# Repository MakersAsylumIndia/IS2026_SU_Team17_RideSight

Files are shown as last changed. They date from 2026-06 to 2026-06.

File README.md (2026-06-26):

# IS2026 Spring - RideSight

Problem Statement-
Motorcycle/Scooter drivers, especially those working for delivery companies, rely heavily on smartphone navigation to complete their journeys. However, checking directions requires them to repeatedly look down at their phones, diverting their attention away from the road. As the number of delivery drivers continues to grow, there is an increased likelihood of them getting into a severe accident, creating an urgent need for a safer, hands-free navigation solution that allows riders to receive directions in real-time.

Solution-
We are developing a smart navigation attachment for a motorcycle helmet with an embedded ESP32 and two RGB LEDs: one on the left and one on the right. The ESP32 will be connected wirelessly over bluetooth to a navigation application on the user's phone. The navigation application will provide real-time instructions, which will be transmitted to the ESP32. The ESP32 will then control the LED lights placed on both sides of the helmet. For example, if the user has to go right, the LED light on the right side of the helmet will blink.

Future Prospects-
This project could be further developed by integrating additional navigation cues and expanding compatibility with different navigation applications. In the future, the system could be adopted by delivery companies to improve rider safety and reduce accidents caused by distracted driving.

Contents of all the folders-
1. **CAD** contains all of the files of the components which we 3D printed/laser cut for our project.
2. **Code** contains the codes for our project.
3. **Documentation** contains the steps to making this project.
4. **Electronics** contains the circuit diagram with all the components which we used for our project.
5. **Photos_Videos** contains photos and videos of the working prototype.
6. **Reference_Data** contains all the references that we used.
7. **BOM.csv** contains all the electrical components that we used.

## License

Licenses

<a href="LICENSE.md">Open Source Licenses Facts</a>

#### Hardware
CERN Open Hardware License Version 2 - Strongly Reciprocal ([CERN-OHL-S-2.0](https://spdx.org/licenses/CERN-OHL-S-2.0.html)).

#### Software
MIT open source [license](http://opensource.org/licenses/MIT).

#### Documentation:
<br />This work is licensed under a <a rel="license" href="http://creativecommons.org/licenses/by/4.0/">Creative Commons Attribution 4.0 International License</a>.

---

## 📬 Contact/Team

> _List team members and contact emails or GitHub profiles._
[@anool](https://github.com/Anool)
> 
>
> ---

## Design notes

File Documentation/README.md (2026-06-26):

We first used Mapbox API and designed a webapp for our navigation system. Then we linked our ESP 32 to this webapp using bluetooth. After finalising the circuit and the components, we designed and 3D printed a box to fit all of the components. This box is supposed to be attached to the helmet using a sliding mechanism which we designed and 3D printed. Finally we mounted the LEDs on the helmet and connected them to the box. The box is detachable so that the user the charge the Li-Po battery inside which powers the entire circuit. The user just has to put the location of where they want to go to on the webapp and the LEDs will indicate direction accordingly.

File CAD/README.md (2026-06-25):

There are files for 3 different components-
the box which we used to store all our electrical components,
the lid for the box which we laser cut,
and the sliding mechanism which we used to easily put on and remove the box from the helmet.

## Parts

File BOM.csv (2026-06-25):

Name of the Material/Component | Quantity | Reference Link | Additional Note
ESP 32 | 1 | https://robocraze.com/products/esp32-development-board?variant=40193649803417&country=IN&currency=INR | Main microcontroller on which the project is based
RGB LEDs | 2 | https://robu.in/product/ws2812b-rgb-addressable-led-module/ | RGB LEDs provide visual cues to the rider and blink in certain patterns telling the driver when to make turns
Battery Charging Module | 1 | https://robu.in/product/tp4056-1a-li-ion-lithium-battery-charging-module-with-current-protection-type-c/ | To charge the battery
LiPo Battery | 1 | https://robu.in/product/wly602540-600mah-3-7v-single-cell-rechargeable-lipo-battery/ | Battery to power the circuit
DC Booster | 1 | https://robu.in/product/xl6009-dc-dc-step-up-converter-performance-ultra-lm2577-booster-circuit-board/ | To boost the 3.7V voltage of the battery to 5V to power the ESP 32
Slide switch | 1 | https://robu.in/product/slide-switch-sk-09/ | To turn the circuit on/off

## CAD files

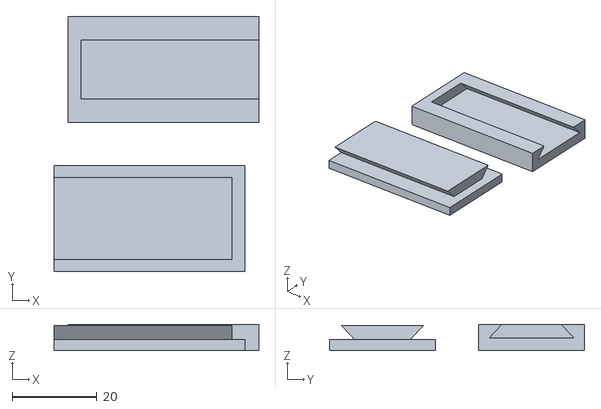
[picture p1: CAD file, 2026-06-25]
CAD/Team 17 MA RideSight Sliding Mechanism STL.stl
48.3 x 60.2 x 6.21

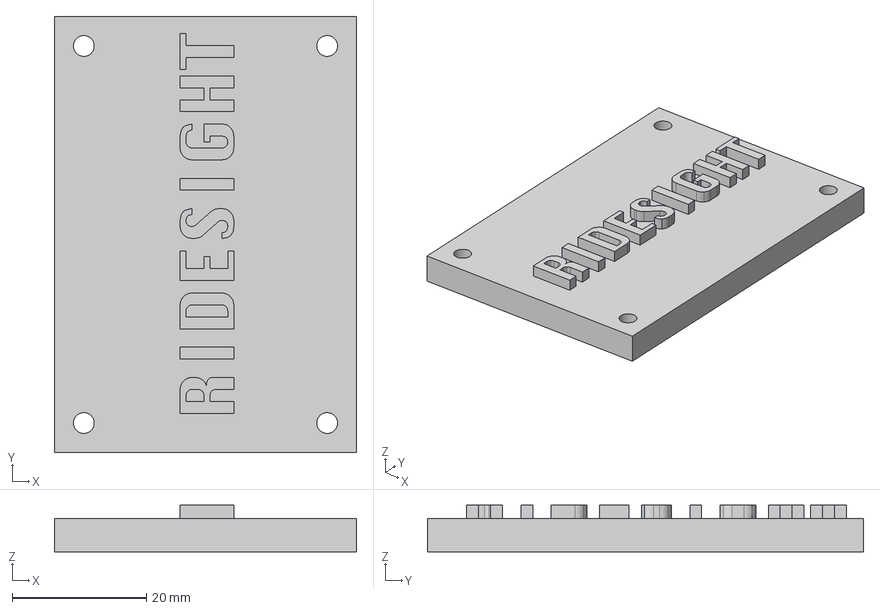
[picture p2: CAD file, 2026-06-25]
CAD/Team 17- Box lid.step
45.0 x 65.0 x 7.00 mm

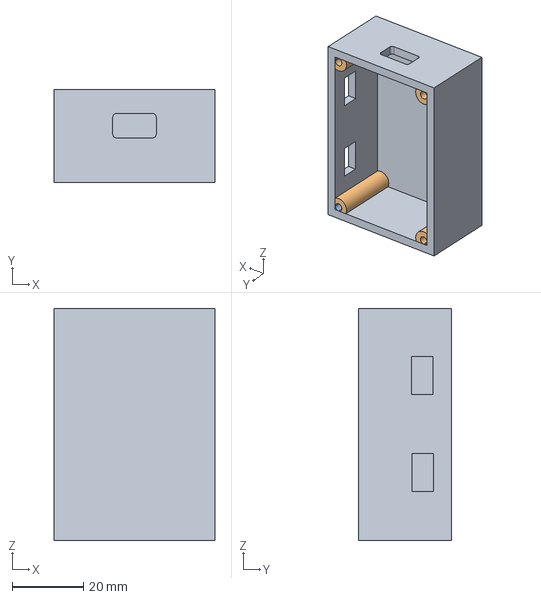
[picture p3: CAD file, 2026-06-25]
CAD/Team17_RideSight_box.step
45.0 x 26.0 x 65.0 mm

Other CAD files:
CAD/Team 17 MA RideSight Sliding Mechanism STEP Format.step
CAD/Team 17 MA RideSight Sliding Mechanism F3D Format.f3d
CAD/Team 17- Box lid.f3d
CAD/Team 17- Box lid.stl
CAD/Team17_RideSight_box.f3d
CAD/Team17_RideSight_box.stl

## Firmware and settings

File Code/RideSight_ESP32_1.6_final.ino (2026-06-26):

/*
 * RideSight — ESP32 (Arduino IDE)  ·  FINAL (Adafruit NeoPixel)
 * Two WS2812B LEDs on separate pins:  right = GPIO5 (D5)   left = GPIO25 (D25)
 * Each pin is its own NeoPixel object (NeoPixel uses one strip per data pin).
 *
 * Functions (5): LEFT_TURN, RIGHT_TURN, LEFT_UTURN, RIGHT_UTURN, ARRIVE  (STRAIGHT = off)
 *
 * Turn  -> respective side LED, SOLID colour by distance:
 *        x > 400        : off
 *        400 >= x > 200 : green
 *        200 >= x > 100 : yellow
 *        100 >= x > 0   : red
 * U-turn -> respective side LED SOLID BLUE when distance < 200 m
 * Arrive -> BOTH LEDs BLINK MAGENTA when distance < 50 m
 *
 * Wire format (3 bytes, must match protocol.js):
 *   byte0 = turn (0=STRAIGHT 1=LEFT_TURN 2=RIGHT_TURN 3=LEFT_UTURN 4=RIGHT_UTURN 5=ARRIVE)
 *   byte1 = distance high byte (uint16 big-endian, metres)   byte2 = distance low byte
 *
 * Libraries (Arduino IDE -> Library Manager):
 *   - "Adafruit NeoPixel"
 *   - "NimBLE-Arduino" (h2zero, 2.x)
 * Board: match your ESP32 variant.  NOTE: GPIO25 doesn't exist on ESP32-C3.
 * Diagnostics (default off): LED_TEST cycles LEDs ignoring BLE; SIMULATE sweeps real patterns.
 */

#include <NimBLEDevice.h>
#include <Adafruit_NeoPixel.h>

// ───────── config ─────────
#define SERVICE_UUID   "6686e2e2-25d8-4172-818f-0886d4e8f695"   // paste EXACT from config.js
#define CHAR_CMD_UUID  "0b64cb22-701b-415d-b32c-26a5483ea35d"
#define DEVICE_NAME    "RideSight"

#define PIN_RIGHT   5      // D5
#define PIN_LEFT    25     // D25

#define BRIGHTNESS            150     // bench-tune against visor glare
#define UTURN_DIST_M          200     // U-turn LED shows under this
#define ARRIVE_DIST_M         50      // magenta flash under this
#define HEARTBEAT_TIMEOUT_MS  3000    // no packet this long -> all off (fail-safe)

#define LED_TEST 0     // 1 = ignore BLE, cycle LEDs to verify wiring/power
#define SIMULATE 0     // 1 = sweep the real patterns with no phone

// packed 0xRRGGBB colours (NeoPixel reorders per NEO_GRB)
#define COL_OFF     0x000000
#define COL_RED     0xFF0000
#define COL_GREEN   0x00FF00
#define COL_BLUE    0x0000FF
#define COL_YELLOW  0xFFFF00
#define COL_MAGENTA 0xFF00FF
#define COL_WHITE   0xFFFFFF

enum Turn : uint8_t { STRAIGHT = 0, LEFT_TURN, RIGHT_TURN, LEFT_UTURN, RIGHT_UTURN, ARRIVE };

// ───────── LEDs (one NeoPixel object per pin) ─────────
Adafruit_NeoPixel right(1, PIN_RIGHT, NEO_GRB + NEO_KHZ800);
Adafruit_NeoPixel left (1, PIN_LEFT,  NEO_GRB + NEO_KHZ800);

// ───────── state ─────────
volatile uint8_t  g_turn   = STRAIGHT;
volatile uint16_t g_dist   = 0;
volatile uint32_t g_lastRx = 0;

static void setLeds(uint32_t l, uint32_t r) {
  left.setPixelColor(0, l);   left.show();
  right.setPixelColor(0, r);  right.show();
}

// ───────── BLE ─────────
class CmdCallbacks : public NimBLECharacteristicCallbacks {
  void onWrite(NimBLECharacteristic* c, NimBLEConnInfo& info) override {
    NimBLEAttValue v = c->getValue();
    if (v.size() >= 3) {
      const uint8_t* p = v.data();
      g_turn   = p[0];
      g_dist   = ((uint16_t)p[1] << 8) | p[2];   // big-endian
      g_lastRx = millis();
      Serial.printf("rx turn=%u dist=%u\n", g_turn, g_dist);
    }
  }
};

static void startBLE() {
  NimBLEDevice::init(DEVICE_NAME);
  NimBLEServer* server = NimBLEDevice::createServer();
  server->advertiseOnDisconnect(true);
  NimBLEService* svc = server->createService(SERVICE_UUID);
  NimBLECharacteristic* cmd = svc->createCharacteristic(
      CHAR_CMD_UUID, NIMBLE_PROPERTY::WRITE | NIMBLE_PROPERTY::WRITE_NR);
  cmd->setCallbacks(new CmdCallbacks());
  svc->start();

  NimBLEAdvertisementData advData;
  advData.setFlags(BLE_HS_ADV_F_DISC_GEN | BLE_HS_ADV_F_BREDR_UNSUP);
  advData.addServiceUUID(SERVICE_UUID);
  NimBLEAdvertisementData scanData;
  scanData.setName(DEVICE_NAME);
  NimBLEAdvertising* adv = NimBLEDevice::getAdvertising();
  adv->setAdvertisementData(advData);
  adv->setScanResponseData(scanData);
  adv->enableScanResponse(true);
  NimBLEDevice::startAdvertising();
}

// distance -> solid zone colour (off above 400 m)
static uint32_t zoneColor(uint16_t x) {
  if (x > 400) return COL_OFF;
  if (x > 200) return COL_GREEN;    // 400..201
  if (x > 100) return COL_YELLOW;   // 200..101
  return COL_RED;                   // 100..0
}

static void bootSelfTest() {
  uint32_t seq[] = { COL_RED, COL_GREEN, COL_BLUE };
  for (uint32_t col : seq) { setLeds(col, col); delay(300); }
  setLeds(COL_OFF, COL_OFF);
}

void setup() {
  Serial.begin(115200);
  delay(200);
  Serial.printf("RideSight FINAL (NeoPixel)  RIGHT=GPIO%d LEFT=GPIO%d  LED_TEST=%d SIMULATE=%d\n",
                PIN_RIGHT, PIN_LEFT, LED_TEST, SIMULATE);

  right.begin(); right.setBrightness(BRIGHTNESS); right.show();
  left.begin();  left.setBrightness(BRIGHTNESS);  left.show();
  bootSelfTest();   // if nothing shows here, it's wiring/power/pin — not BLE/website

#if !LED_TEST && !SIMULATE
  startBLE();
  Serial.println("RideSight advertising…");
#endif
}

void loop() {
  uint32_t now = millis();

#if LED_TEST
  uint32_t test[] = { COL_RED, COL_GREEN, COL_BLUE, COL_WHITE };
  uint32_t c = test[(now / 700) % 4];
  setLeds(c, c); delay(10); return;
#endif

#if SIMULATE
  struct Case { uint8_t turn; uint16_t dist; };
  static const Case cases[] = {
    {LEFT_TURN,350},{LEFT_TURN,150},{LEFT_TURN,60},
    {RIGHT_TURN,150},{LEFT_UTURN,150},{RIGHT_UTURN,150},{ARRIVE,40},
  };
  const Case& c = cases[(now / 3000) % (sizeof(cases)/sizeof(cases[0]))];
  g_turn = c.turn; g_dist = c.dist; g_lastRx = now;
#endif

  uint8_t  turn = g_turn;
  uint16_t dist = g_dist;
  uint32_t lColor = COL_OFF, rColor = COL_OFF;

  bool haveData = (g_lastRx != 0);
  bool stale    = haveData && (now - g_lastRx > HEARTBEAT_TIMEOUT_MS);

  if (haveData && !stale) {
    switch (turn) {
      case LEFT_TURN:   lColor = zoneColor(dist); break;   // solid, no blink
      case RIGHT_TURN:  rColor = zoneColor(dist); break;
      case LEFT_UTURN:  if (dist < UTURN_DIST_M) lColor = COL_BLUE; break;
      case RIGHT_UTURN: if (dist < UTURN_DIST_M) rColor = COL_BLUE; break;
      case ARRIVE:
        if (dist < ARRIVE_DIST_M && ((now / 250) % 2))       // ~2 Hz flash
          lColor = rColor = COL_MAGENTA;
        break;
      case STRAIGHT:
      default: break;
    }
  }

  setLeds(lColor, rColor);
  delay(10);
}

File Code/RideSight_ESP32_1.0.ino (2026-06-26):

/*
 * RideSight — ESP32 (Arduino IDE)
 * Three WS2812B LEDs on SEPARATE data pins:
 *   left = GPIO5 (D5), centre = GPIO18 (D18), right = GPIO19 (D19)
 *
 * LED behaviour (this version):
 *   RIGHT_TURN  -> fade the RIGHT LED  (breathing fade)
 *   LEFT_TURN   -> fade the LEFT  LED  (breathing fade)
 *   LEFT_UTURN  -> LEFT  LED solid BLUE when distance < 500 m (else off)
 *   RIGHT_UTURN -> RIGHT LED solid BLUE when distance < 500 m (else off)
 *   STRAIGHT    -> nothing (centre LED has no assigned pattern yet)
 *
 * turn + distance arrive over BLE from the phone (3-byte payload, must match
 * the web app's protocol.js):
 *   byte 0 = turn (0=STRAIGHT 1=LEFT_TURN 2=RIGHT_TURN 3=LEFT_UTURN 4=RIGHT_UTURN)
 *   byte 1 = distance high byte (uint16, big-endian, metres)
 *   byte 2 = distance low  byte
 *
 * Libraries (Arduino IDE -> Library Manager):
 *   - "NimBLE-Arduino" by h2zero   (this code needs 2.x)
 *   - "FastLED"
 * Board: "ESP32 Dev Module" (Espressif esp32 core).
 */

#include <NimBLEDevice.h>
#include <FastLED.h>

// ───────── config ─────────
// Paste the EXACT UUIDs from your web app's src/config.js (prefixes are hints).
#define SERVICE_UUID   "6686e2e2-25d8-4172-818f-0886d4e8f695"
#define CHAR_CMD_UUID  "0b64cb22-701b-415d-b32c-26a5483ea35d"
#define DEVICE_NAME    "RideSight"

#define PIN_LEFT    5     // D5
#define PIN_CENTRE  18    // D18
#define PIN_RIGHT   19    // D19

#define BRIGHTNESS        100  // global ceiling — BENCH-TUNE against visor glare
#define FADE_BPM          30    // breathing fade speed (breaths/min) — tunable
#define TURN_HUE          32    // fade colour for turns (FastLED HSV: ~32 = amber). Blue is reserved for U-turns.
#define UTURN_DIST_M      500   // U-turn LED shows only under this distance
#define HEARTBEAT_TIMEOUT_MS 3000  // no packet this long -> LEDs off (fail-safe)

#define SIMULATE 0       // set to 1 to cycle the patterns WITHOUT a phone (bench test)

enum Turn : uint8_t { STRAIGHT = 0, LEFT_TURN, RIGHT_TURN, LEFT_UTURN, RIGHT_UTURN };

// ───────── state ─────────
CRGB ledLeft[1], ledCentre[1], ledRight[1];
volatile uint8_t  g_turn   = STRAIGHT;
volatile uint16_t g_dist   = 0;
volatile uint32_t g_lastRx = 0;

// ───────── BLE ─────────
class CmdCallbacks : public NimBLECharacteristicCallbacks {
  void onWrite(NimBLECharacteristic* c, NimBLEConnInfo& info) override {
    NimBLEAttValue v = c->getValue();
    if (v.size() >= 3) {
      const uint8_t* p = v.data();
      g_turn   = p[0];
      g_dist   = ((uint16_t)p[1] << 8) | p[2];   // big-endian
      g_lastRx = millis();
    }
  }
};

static void startBLE() {
  NimBLEDevice::init(DEVICE_NAME);
  NimBLEServer* server = NimBLEDevice::createServer();
  server->advertiseOnDisconnect(true);           // 2.x: auto re-advertise is OFF by default

  NimBLEService* svc = server->createService(SERVICE_UUID);
  NimBLECharacteristic* cmd = svc->createCharacteristic(
      CHAR_CMD_UUID, NIMBLE_PROPERTY::WRITE | NIMBLE_PROPERTY::WRITE_NR);
  cmd->setCallbacks(new CmdCallbacks());
  svc->start();

  // Service UUID in the MAIN advertisement packet (Web Bluetooth / Bluefy filter
  // on it); device NAME in the scan response (both won't fit in 31 bytes).
  NimBLEAdvertisementData advData;
  advData.setFlags(BLE_HS_ADV_F_DISC_GEN | BLE_HS_ADV_F_BREDR_UNSUP);
  advData.addServiceUUID(SERVICE_UUID);
  NimBLEAdvertisementData scanData;
  scanData.setName(DEVICE_NAME);

  NimBLEAdvertising* adv = NimBLEDevice::getAdvertising();
  adv->setAdvertisementData(advData);
  adv->setScanResponseData(scanData);
  adv->enableScanResponse(true);                 // 2.x: must enable explicitly
  NimBLEDevice::startAdvertising();
}

// ───────── boot self-test: R, G, B on each LED so you can verify wiring/colour ─────────
static void bootSelfTest() {
  const CRGB seq[] = { CRGB::Red, CRGB::Green, CRGB::Blue };
  for (CRGB col : seq) {
    ledLeft[0] = ledCentre[0] = ledRight[0] = col;
    FastLED.show();
    delay(250);
  }
  ledLeft[0] = ledCentre[0] = ledRight[0] = CRGB::Black;
  FastLED.show();
}

void setup() {
  Serial.begin(115200);
  FastLED.addLeds<WS2812B, PIN_LEFT,   GRB>(ledLeft,   1);
  FastLED.addLeds<WS2812B, PIN_CENTRE, GRB>(ledCentre, 1);
  FastLED.addLeds<WS2812B, PIN_RIGHT,  GRB>(ledRight,  1);
  FastLED.setBrightness(BRIGHTNESS);
  bootSelfTest();
#if !SIMULATE
  startBLE();
  Serial.println("RideSight advertising…");
#else
  Serial.println("RideSight SIMULATE mode");
#endif
}

void loop() {
  uint32_t now = millis();

#if SIMULATE
  // cycle the four maneuvers every 4 s; distance fixed under 500 m so U-turns show
  const uint8_t cyc[] = { LEFT_TURN, RIGHT_TURN, LEFT_UTURN, RIGHT_UTURN };
  g_turn   = cyc[(now / 4000) % 4];
  g_dist   = 300;
  g_lastRx = now;
#endif

  uint8_t  turn = g_turn;
  uint16_t dist = g_dist;

  ledLeft[0] = ledCentre[0] = ledRight[0] = CRGB::Black;   // clear each frame

  bool haveData = (g_lastRx != 0);
  bool stale    = haveData && (now - g_lastRx > HEARTBEAT_TIMEOUT_MS);

  if (haveData && !stale) {
    uint8_t fade = beatsin8(FADE_BPM, 0, 255);   // breathing brightness 0..255
    switch (turn) {
      case LEFT_TURN:   ledLeft[0]  = CHSV(TURN_HUE, 255, fade); break;
      case RIGHT_TURN:  ledRight[0] = CHSV(TURN_HUE, 255, fade); break;
      case LEFT_UTURN:  if (dist < UTURN_DIST_M) ledLeft[0]  = CRGB::Blue; break;
      case RIGHT_UTURN: if (dist < UTURN_DIST_M) ledRight[0] = CRGB::Blue; break;
      case STRAIGHT:
      default: break;   // centre (D18) has no assigned pattern yet
    }
  }

  FastLED.show();
  delay(10);   // ~100 Hz; fade timing is millis-based, not delay-based
}

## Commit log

2026-06-22 Rename Testing to Testing for ONE LED strip
2026-06-22 Create All three LED testing
2026-06-23 Create SINGLE LED on ONE ring testing
2026-06-23 Create NEW LEDS TEST CODE
2026-06-25 Create Final Circuit Diagram
2026-06-26 Create Circuit
